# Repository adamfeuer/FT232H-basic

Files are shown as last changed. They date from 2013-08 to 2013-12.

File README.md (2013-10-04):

FT232H-basic
============

This is an FTDI FT232H to USART basic breakout board - it can do USB 2.0 High Speed, and up to 10Mbps 
on the USART interface.

It has USB 2.0 High Speed ESD protection and a resettable fuse on the power input.

This board has been made, tested, and works for send and receive at USB 2.0 HS speeds. 

Known issues
============

TX and RX LEDs did not work on the 0.4.2 version of the board - because the signals are active low,
and needed to be connected to 3.3V via a 470 ohm resistor. This has been fixed.

If you have questions, comments, or improvements, I would love to know them!

cheers<br>
adam<br>
Adam Feuer<br>
Seattle, WA, USA<br>
adam@adamfeuer.com<br>
http://adamfeuer.com<br>

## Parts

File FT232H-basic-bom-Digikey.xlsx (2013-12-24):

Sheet: Digikey order
Digi-Key Part # | Manufacturer | Manufacturer's Part # | Reference | Quantity 1 | Quantity 2 | Part | Value | Comments | Package | Description | Vendor
399-1282-1-ND |  |  |  | 5 |  | C1 | 0.1uF | 0.1UF-25V-5%(0603) | 0603-CAP | CAP-08604 | Digikey
MCT0603-10.0K-MFCT-ND |  |  |  | 1 |  | R1 | 10K | 10KOHM1/10W1%(0603)0603 | 0603-RES | RES-00824 | Digikey
399-7839-1-ND |  |  |  | 1 |  | C6 | 10nF | 0.1UF-25V-5%(0603) | 0603-CAP | CAP-08604 | Digikey
1276-1869-1-ND |  |  |  | 2 |  | C7 | 10uF | 0.1UF-25V-5%(0603) | 0603-CAP | CAP-08604 | Digikey
541-12.0KHCT-ND |  |  |  | 1 |  | R2 | 12K | RESISTOR0603 | 0603-RES | Resistor | Digikey
887-1292-2-ND |  |  |  | 1 |  | OSC1 | 12Mhz | CRYSTAL5X3 | CRYSTAL-SMD-5X3 | Various standard crystals. Proven footprints. Spark Fun Electronics SKU : COM-00534 | Digikey
MCT0603-1.00K-MFCT-ND |  |  |  | 1 |  | R3 | 1k | 1K-1% | 0603-RES | 1k-ohm SMT | Digikey
P470GCT-ND |  |  |  | 2 |  | R3, R4 | 470 | 470-1% | 0603-RES | 1k-ohm SMT | Digikey
399-9053-1-ND |  |  |  | 2 |  | C2 | 27pF | 0.1UF-25V-5%(0603) | 0603-CAP | CAP-08604 | Digikey
445-6157-1-ND |  |  |  | 1 |  | L1 | 600R/500ma | INDUCTOR0603 | 603 | Inductors | Digikey
768-1101-1-ND |  |  |  | 1 |  | IC1 | FT232H | FT232H | LQFP48 | FTDI FT232H | Digikey
160-1183-2-ND |  |  |  | 2 |  | LED1 | GREEN | LED-GREEN0603 | LED-0603 | Various green LEDs | Digikey
568-3529-1-ND |  |  |  | 1 |  | ESD1 | IP4220CZ6 | IP4220CZ6 | SSOT-6 | IP4220CZ6 - USB HS ESD protection | Digikey
160-1184-2-ND |  |  |  | 1 |  | LED3 | YELLOW | LED-YELLOW0603 | LED-0603 | Yellow SMD LEDs | Digikey
NA |  |  |  | 1 |  | JP1 |  | M06SMD-FEMALE-V2 | 1X06-SMD-FEMALE-V2 | Header 6 | Sparkfun
WM17121-ND | Molex |  |  | 1 |  | USB1 |  | USB-MINIBTH-SLOT | USB-MINI-AB-TH-MOLEX-SLOT | USB Connectors | Digikey
F4150CT-ND | Littelfuse |  |  | 1 |  | F1 |  | 0603L050YR Littelfuse | PTC0603 | Resettable Fuse | Digikey

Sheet: Build BOM
FT232H Basic
Done? | Part | Value | Device | Package | Description | PROD_ID | VALUE
 | C1 | 0.1uF | 0.1UF-25V-5%(0603) | 0603-CAP | CAP-08604 | CAP-08604 | 0.1uF
 | C3 | 0.1uF | 0.1UF-25V-5%(0603) | 0603-CAP | CAP-08604 | CAP-08604 | 0.1uF
 | C5 | 0.1uF | 0.1UF-25V-5%(0603) | 0603-CAP | CAP-08604 | CAP-08604 | 0.1uF
 | C9 | 0.1uF | 0.1UF-25V-5%(0603) | 0603-CAP | CAP-08604 | CAP-08604 | 0.1uF
 | C10 | 0.1uF | 0.1UF-25V-5%(0603) | 0603-CAP | CAP-08604 | CAP-08604 | 0.1uF
 | C11 | 0.1uF | 0.1UF-25V-5%(0603) | 0603-CAP | CAP-08604 | CAP-08604 | 0.1uF
 | R1 | 10K | 10KOHM1/10W1%(0603)0603 | 0603-RES | RES-00824 | RES-00824 | 10K
 | C6 | 10nF | 0.1UF-25V-5%(0603) | 0603-CAP | CAP-08604 | CAP-08604 | 0.1uF
 | C7 | 10uF | 0.1UF-25V-5%(0603) | 0603-CAP | CAP-08604 | CAP-08604 | 0.1uF
 | C8 | 10uF | 0.1UF-25V-5%(0603) | 0603-CAP | CAP-08604 | CAP-08604 | 0.1uF
 | R2 | 12K | RESISTOR0603 | 0603-RES | Resistor
 | OSC1 | 12Mhz | CRYSTAL5X3 | CRYSTAL-SMD-5X3 | Various standard crystals. Proven footprints. Spark Fun Electronics SKU : COM-00534
 | R3 | 1k | 1K-1% | 0603-RES | 1k-ohm SMT | RES-07856 | 1k
 | R4 | 470 | 470-1% | 0603-RES | 470-ohm SMT | RES-07856 | 1k
 | R5 | 470 | 470-1% | 0603-RES | 470-ohm SMT | RES-07856 | 1k
 | C2 | 27pF | 0.1UF-25V-5%(0603) | 0603-CAP | CAP-08604 | CAP-08604 | 0.1uF
 | C4 | 27pF | 0.1UF-25V-5%(0603) | 0603-CAP | CAP-08604 | CAP-08604 | 0.1uF
 | L1 | 600R/500ma | INDUCTOR0603 | 603 | Inductors
 | IC1 | FT232H | FT232H | LQFP48 | FTDI FT232H
 | LED1 | GREEN | LED-GREEN0603 | LED-0603 | Various green LEDs | DIO-00821 | GREEN
 | LED2 | GREEN | LED-GREEN0603 | LED-0603 | Various green LEDs | DIO-00821 | GREEN
 | ESD1 | NUF2042XV6SOT563 | NUF2042XV6SOT563 | SOT563 | NUF2042XV6 - USB ESD protection, and Full-speed USB termination.
 | LED3 | YELLOW | LED-YELLOW0603 | LED-0603 | Yellow SMD LEDs | DIO-09003
 | JP1 |  | M06SMD-FEMALE-V2 | 1X06-SMD-FEMALE-V2 | Header 6
 | USB1 |  | USB-MINIBTH-SLOT | USB-MINI-AB-TH-MOLEX-SLOT | USB Connectors

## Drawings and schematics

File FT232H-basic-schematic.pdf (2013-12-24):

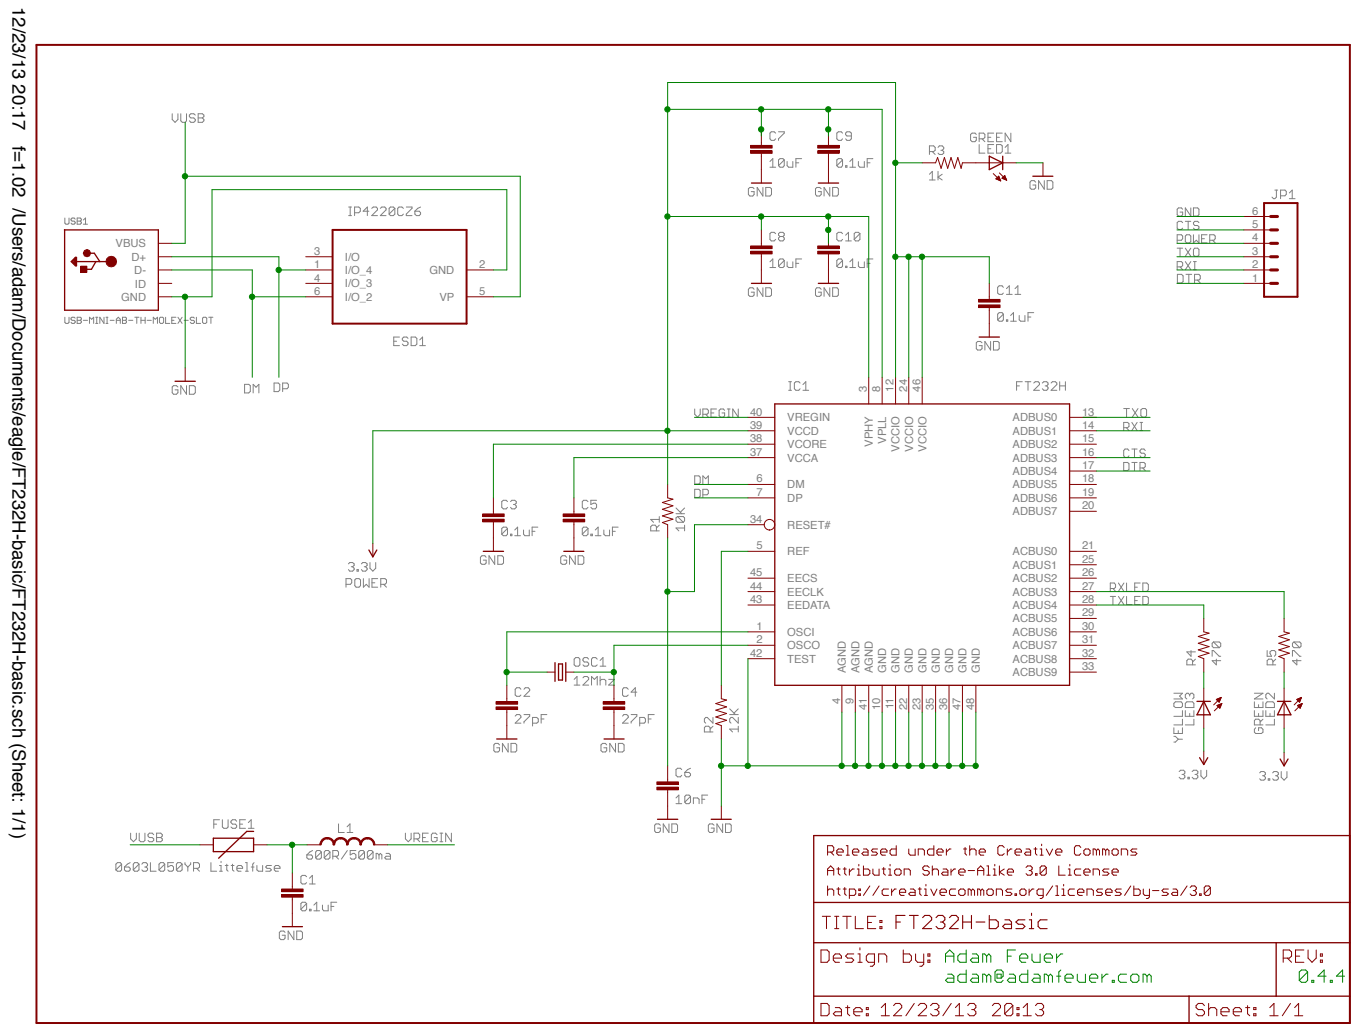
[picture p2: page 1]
OSCI 1 OSCO 2; VPHY 3; AGND 4; REF 5; VPLL 8; AGND 9; GND 10; GND 11 VCCIO 12; ADBUS0; ADBUS1; ADBUS2; ADBUS3; ADBUS4; ADBUS5; ADBUS6; ADBUS7; ACBUS0; GND 22; GND 23 VCCIO 24; ACBUS1; ACBUS2; ACBUS3; ACBUS4; ACBUS5; ACBUS6; ACBUS7; ACBUS8; ACBUS9; RESET# 34; GND 35; GND 36; VCCA 37; VCORE 38; VCCD 39; VREGIN 40; AGND 41; TEST 42; EEDATA 43; EECLK 44; EECS 45; VCCIO 46; GND 47; GND 48; VBUS; GND

12/23/13 20:17 f=1.02 /Users/adam/Documents/eagle/FT232H-basic/FT232H-basic.sch (Sheet: 1/1)

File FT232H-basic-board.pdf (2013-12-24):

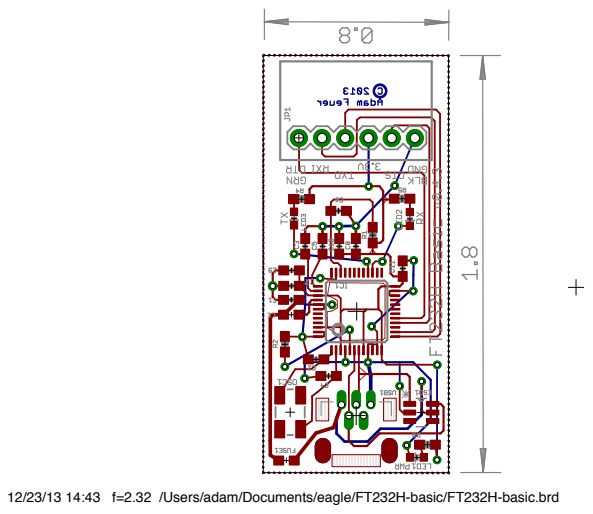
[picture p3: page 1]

12/23/13 14:43 f=2.32 /Users/adam/Documents/eagle/FT232H-basic/FT232H-basic.brd

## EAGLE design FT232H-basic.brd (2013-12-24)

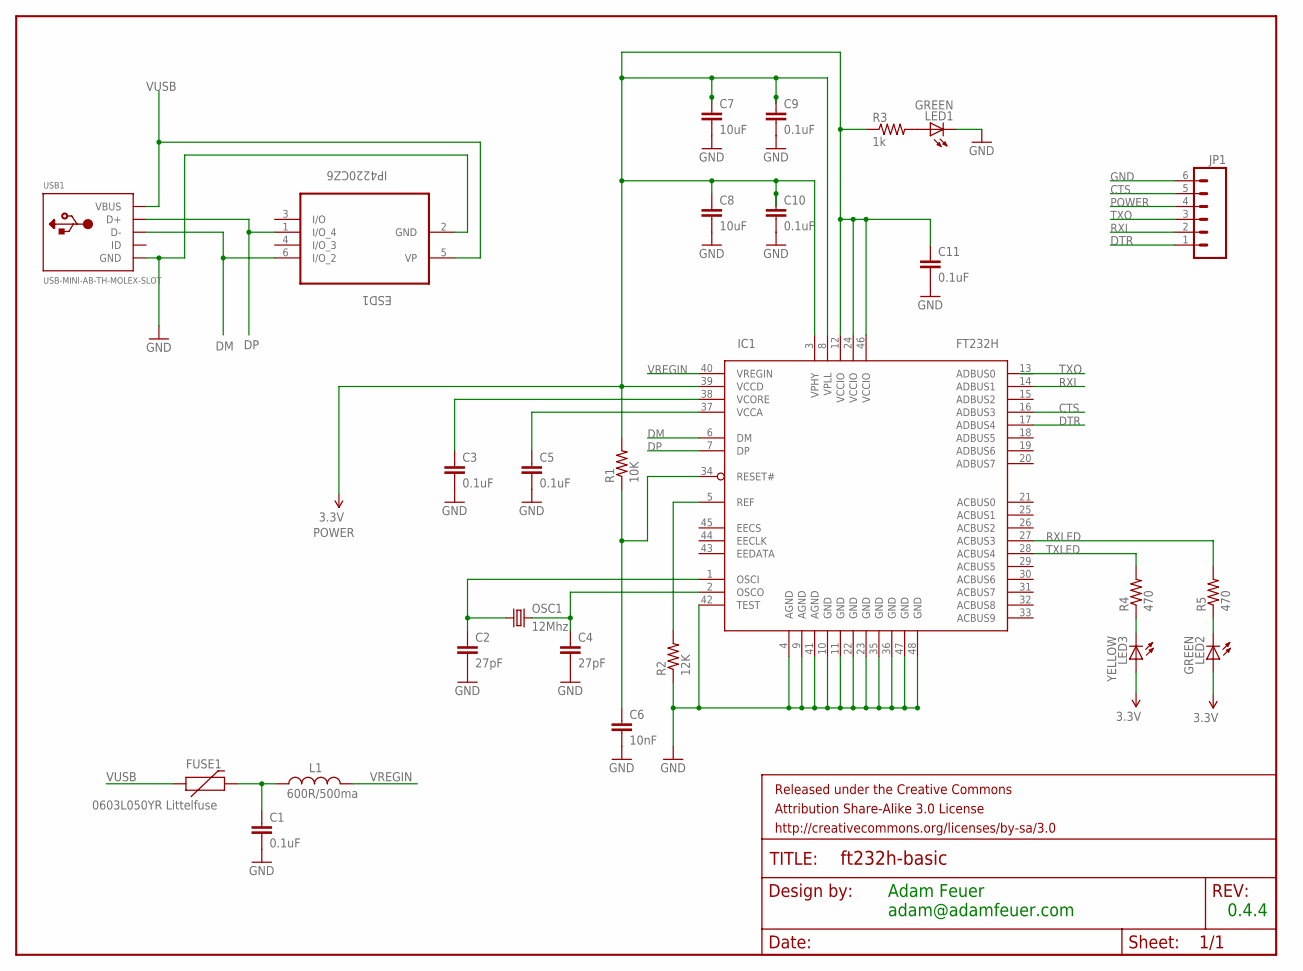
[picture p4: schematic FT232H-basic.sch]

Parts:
C1, C3, C5, C9, C10, C11: 0.1uF; 0603-CAP
C2, C4: 27pF; 0603-CAP
C6: 10nF; 0603-CAP
C7, C8: 10uF; 0603-CAP
ESD1: IP4220CZ6; SOT95P275X110-6N
FRAME1: FRAME-LETTER; CREATIVE_COMMONS
FUSE1: 0603L050YR Littelfuse; 0603
IC1: FT232H; LQFP48
JP1: M06SIP; 1X06
L1: 600R/500ma; 0603
LED1, LED2: GREEN; LED-0603
LED3: YELLOW; LED-0603
OSC1: 12Mhz; CRYSTAL-SMD-5X3
R1: 10K; 0603-RES
R2: 12K; 0603-RES
R3: 1k; 0603-RES
R4, R5: 470; 0603-RES
USB1: USB-MINI-AB-TH-MOLEX-SLOT

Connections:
CTS: IC1.16 (ADBUS3), JP1.5
DM: ESD1.6 (I/O_2), IC1.6 (DM), USB1.D-
DP: ESD1.1 (I/O_4), IC1.7 (DP), USB1.D+
DTR: IC1.17 (ADBUS4), JP1.1
GND: C1.2, C2.2, C3.2, C4.2, C5.2, C6.2, C7.2, C8.2, C9.2, C10.2, C11.2, ESD1.2 (GND), IC1.4 (AGND), IC1.9 (AGND), IC1.10 (GND), IC1.11 (GND), IC1.22 (GND), IC1.23 (GND), IC1.35 (GND), IC1.36 (GND), IC1.41 (AGND), IC1.42 (TEST), IC1.47 (GND), IC1.48 (GND), JP1.6, LED1.C, R2.1, USB1.GND
unnamed: C5.1, IC1.37 (VCCA)
unnamed: C3.1, IC1.38 (VCORE)
unnamed: C6.1, IC1.34 (RESET#), R1.1
unnamed: IC1.5 (REF), R2.2
unnamed: LED1.A, R3.2
unnamed: C1.1, FUSE1.2, L1.1
unnamed: C4.1, IC1.2 (OSCO), OSC1.3 (2)
unnamed: LED3.C, R4.1
unnamed: LED2.C, R5.1
OSC1: C2.1, IC1.1 (OSCI), OSC1.1
POWER: C7.1, C8.1, C9.1, C10.1, C11.1, IC1.3 (VPHY), IC1.8 (VPLL), IC1.12 (VCCIO), IC1.24 (VCCIO), IC1.39 (VCCD), IC1.46 (VCCIO), JP1.4, LED2.A, LED3.A, R1.2, R3.1
RXI: IC1.14 (ADBUS1), JP1.2
RXLED: IC1.27 (ACBUS3), R5.2
TXLED: IC1.28 (ACBUS4), R4.2
TXO: IC1.13 (ADBUS0), JP1.3
VREGIN: IC1.40 (VREGIN), L1.2
VUSB: ESD1.5 (VP), FUSE1.1, USB1.VBUS

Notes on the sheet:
Adam Feuer adam@adamfeuer.com
0.4.4

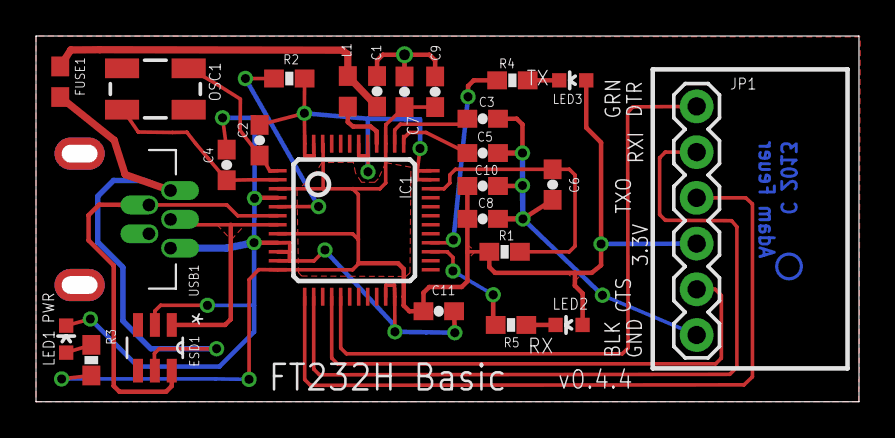
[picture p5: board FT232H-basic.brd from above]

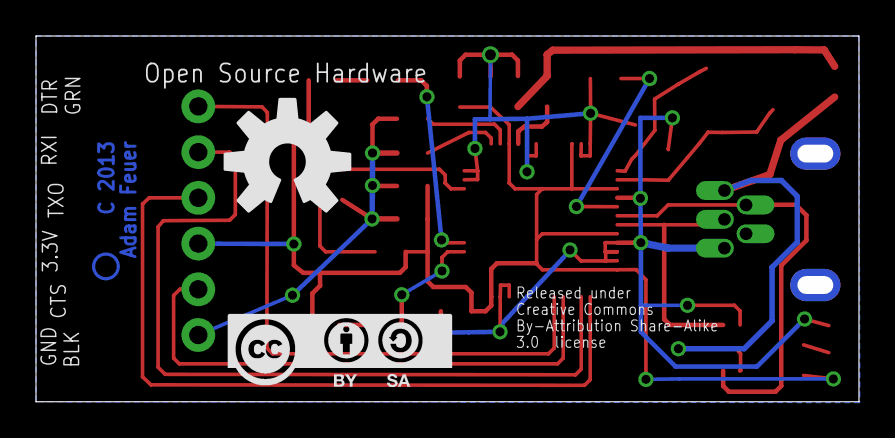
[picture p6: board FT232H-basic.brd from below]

Board: 2 copper layers, 45.7 x 20.3 mm, 29 parts (2 on the bottom side), 22 nets.

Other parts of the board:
CC-BY-SA-LOGO: CC-BY-SA
U$1: OSHW-LOGO-L

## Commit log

2013-08-16 initial addition of schematic for FT232H basic board
    [FT232H-basic.sch]
2013-08-17 initial addition of board file - board fully routed, but still a mess
    [FT232H-basic.brd]
2013-08-21 routing improvements - much simpler, has bottom ground plane and top copper pour
    [FT232H-basic.brd, FT232H-basic.sch]
2013-08-21 board is slightly smaller now; traces in ground plane shorter
    [FT232H-basic.brd]
2013-08-22 board is slightly smaller again, using space under TTL connector for traces
    [FT232H-basic.brd]
2013-08-22 reduced board width
    [FT232H-basic.brd]
2013-08-23 board routed, passes DRC, and has silkscreen; not all fonts are vector
    [FT232H-basic.brd, FT232H-basic.sch]
2013-08-23 changed all fonts to vector (by smashing all parts)
    [FT232H-basic.brd]
2013-08-28 minor changes - removed CC logo from schematic (still on board); made layers visible
    [FT232H-basic.brd, FT232H-basic.sch]
2013-08-29 adding schematic pdf
2013-08-29 added note about 1x6 surface mount female header availability
2013-08-30 changed out ESD IC to USB 2.0 HS - NXP IP4220CZ6 ; added LittelFuse 0603; changed out connector to 1x06 female through hole
    [FT232H-basic.brd, FT232H-basic.sch]
2013-08-30 updated PDF schematic and readme
2013-08-31 added bounding box for 1x06 female header
    [FT232H-basic.brd]
2013-09-05 after v0.1 back from OSH Park: made part names larger, bumped version to 0.3
    [FT232H-basic.brd, FT232H-basic.sch]
2013-09-05 moved USB connector name to be actually on the board
    [FT232H-basic.brd]
2013-09-06 board passes ERC
    [FT232H-basic.brd, FT232H-basic.sch]
2013-09-06 added Digikey BOMs
    [FT232H-basic-bom-Digikey.csv, FT232H-basic-bom-Digikey.xlsx]
2013-09-06 minor changes to silkscreen
    [FT232H-basic.brd]
2013-09-07 rerouted USART traces to keep them on top side of board, shortened paths - for high speed routing
    [FT232H-basic.brd]
2013-09-07 rerouted USB DP and DM traces to make them more direct - for high speed routing
    [FT232H-basic.brd]
2013-09-07 rerouted USB DP and DM traces to be entirely on top of board, with shorter paths
    [FT232H-basic.brd]
2013-09-07 updated schematic to reflect correct size 0603 of FUSE1
    [FT232H-basic.brd, FT232H-basic.sch]
2013-09-08 rerouted board to make USB DM and DP signals as short as possible; USART data signals are on top of board; board is slightly wider; version bumped to 0.4
    [FT232H-basic.brd]
2013-09-08 fixed error with TX LED being in wrong place - power LED is now in lower left, TX in upper right-middle
    [FT232H-basic.brd]
2013-09-08 minor cosmetic changes to polygons
    [FT232H-basic.brd]
2013-09-09 replaced decoupling capacitors close to chip; rerouted board
    [FT232H-basic.brd]
2013-09-09 moved OSC1 traces so they are not serpentine
    [FT232H-basic.brd, FT232H-basic.sch]
2013-09-13 moved VUSB trace so it doesn't cross under USB DP and DM - so there is only ground plane under the high speed traces
    [FT232H-basic.brd]
2013-10-02 updated readme to say board is tested
2013-10-02 minor updates to board legend; added BOM files and board PDF
    [FT232H-basic-bom-Digikey.xlsx, FT232H-basic-bom.csv, FT232H-basic.brd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]
2013-10-04 fixed TX/RX led bug - TX/RX signals are active low, so need to be connected to power via 47O ohm resistor, as per UM232H datasheet
    [FT232H-basic.brd, FT232H-basic.sch]
2013-10-04 updated readme re: fixed TX/RX LEDS
2013-11-10 fixed LED orientation - anode faces power
    [FT232H-basic.brd, FT232H-basic.sch]
2013-11-25 updated bom spreadsheet
    [FT232H-basic-bom-Digikey.xlsx]
2013-12-24 corrected RX and TX LED circuit
    [FT232H-basic-bom-Digikey.xlsx, FT232H-basic.brd, FT232H-basic.sch]

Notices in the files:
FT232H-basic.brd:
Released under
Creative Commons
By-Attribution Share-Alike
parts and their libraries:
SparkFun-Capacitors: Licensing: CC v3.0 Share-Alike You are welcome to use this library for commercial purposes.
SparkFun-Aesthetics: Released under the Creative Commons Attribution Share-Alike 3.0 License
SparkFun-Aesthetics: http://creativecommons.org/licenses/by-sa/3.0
